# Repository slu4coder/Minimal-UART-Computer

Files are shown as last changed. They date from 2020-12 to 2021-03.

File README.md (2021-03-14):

# Minimal UART Computer - older version with EEPROMs

Current version: https://github.com/slu4coder/Minimal-UART-CPU-FLASH-Edition

Hi there, I built my own Computer from scratch - using nothing but TTL chips, because, well, that's what I wanted to do, I guess! I wanted
a CPU that is easy to understand, fun to build and powerful enough to allow for programming educational stuff and little games on it.
Ah, and by the way - it should be as simple as possible - sort of the "Simplest Usable Personal Computer Ever". Well, in case you're
interested, this repo aims to provide you with everything you need to follow my one-and-a-half year journey down this rabbit hole. 

WHAT YOU GET HERE:

  ● Block diagram of the CPU and overview it's instruction set

  ● KiCAD project files with detailed schematics and PCB layout

  ● Gerber files ready to be submitted at any PCB manufacturer of your choice

  ● Bill of material

  ● Images in .bin format of both the ROM and the CPU's control microcode

  ● Source code of the minimal operating system MinOS and several demos and games

  ● Cross-assembler 'asm.exe' running on Windows in order to comfortably write, assemble and upload your own software

TECHNICAL SPECIFICATION:

  ● Comparable to Altair 8800 or Apple 1

  ● Clear(est?) and simple(st? – you judge!) design for fun and education

  ● 8-bit data bus, 16-bit address bus, Von-Neumann architecture

  ● 64 instructions (conditional branching, subroutines, stack and word ops)

  ● 1,8432MHz clock with 0.25Mips (Altair 8800: 0.29Mips, Apple 1: 0.43Mips)

  ● 24kB RAM / 8kB ROM (OS, memory monitor, disassembler, tools, games)

  ● UART interface (115.2kbps) for terminal display, keyboard input and file I/O

  ● 16 control signals, 2 registers A and B, ALU (arithmetic and logic unit) = simple adder, 3 flags (negative, carry and zero)

  ● Built from 74HCxx TTL logic on 120mm x 190mm PCB

I hope you find this information useful, educational or otherwise interesting. I'd love to hear about you build, so meet me on YouTube.

https://www.youtube.com/channel/UCXYQcMpUBT3aaQKfmAVJNow

Cheers,
Slu4

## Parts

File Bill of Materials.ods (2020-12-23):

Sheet: BOM sorted by reference
Ref | Value | Footprint
C1-C9 | 100nF | Capacitor_THT:C_Disc_D5.0mm_W2.5mm_P2.50mm
C10 | 100pF | Capacitor_THT:C_Disc_D5.0mm_W2.5mm_P2.50mm
C11-C51 | 100nF | Capacitor_THT:C_Disc_D5.0mm_W2.5mm_P2.50mm
C52 | 47µF | Capacitor_THT:CP_Radial_D7.5mm_P2.50mm
J1 | UART | Connector_PinSocket_1x06_P2.54mm_Vertical
R1-R8 | 470 | Resistor_THT_Axial_L6.3mm_D2.5mm_P7.62mm_Horizontal
R9 | 10k | Resistor_THT_Axial_L6.3mm_D2.5mm_P7.62mm_Horizontal
R10 | jumper wire | Resistor_THT_Axial_L6.3mm_D2.5mm_P7.62mm_Horizontal
SW1 | RESET | Button_Switch_THT:SW_PUSH_6mm
U1 | 74HC04 | Package_DIP:DIP-14_W7.62mm
U2 | 74HC173 | Package_DIP:DIP-16_W7.62mm
U3 | 74HC173 | Package_DIP:DIP-16_W7.62mm
U4 | 74HC245 | Package_DIP:DIP-20_W7.62mm
U5 | 74HC173 | Package_DIP:DIP-16_W7.62mm
U6 | 74HC173 | Package_DIP:DIP-16_W7.62mm
U7 | AT28C64B CTRL MSB | Package_DIP:DIP-28_W15.24mm_Socket
U8 | 74HC173 | Package_DIP:DIP-16_W7.62mm
U9 | AT28C64B CTRL LSB | Package_DIP:DIP-28_W15.24mm_Socket
U10 | 74HC173 | Package_DIP:DIP-16_W7.62mm
U11 | 74HC161 | Package_DIP:DIP-16_W7.62mm
U12 | 74HC86 | Package_DIP:DIP-14_W7.62mm
U13 | 74HC283 | Package_DIP:DIP-16_W7.62mm
U14 | 74HC283 | Package_DIP:DIP-16_W7.62mm
U15 | 74HC245 | Package_DIP:DIP-20_W7.62mm
U16 | 74HC86 | Package_DIP:DIP-14_W7.62mm
U17 | 74HC173 | Package_DIP:DIP-16_W7.62mm
U18 | 74HC02 | Package_DIP:DIP-14_W7.62mm
U19 | 74HC08 | Package_DIP:DIP-14_W7.62mm
U23 | 74HC245 | Package_DIP:DIP-20_W7.62mm
U24 | 74HC32 | Package_DIP:DIP-14_W7.62mm
U26 | 74HC161 | Package_DIP:DIP-16_W7.62mm
U28 | 74HC161 | Package_DIP:DIP-16_W7.62mm
U29 | 74HC32 | Package_DIP:DIP-14_W7.62mm
U30 | 74HC161 | Package_DIP:DIP-16_W7.62mm
U31 | AT28C64B 8k ROM | Package_DIP:DIP-28_W15.24mm_Socket
U32 | CY62256 32k RAM | Package_DIP:DIP-28_W15.24mm
U33 | 74HC161 | Package_DIP:DIP-16_W7.62mm
U34 | 74HC161 | Package_DIP:DIP-16_W7.62mm
U35 | 74HC00 | Package_DIP:DIP-14_W7.62mm
U36 | 74HC173 | Package_DIP:DIP-16_W7.62mm
U37 | 74HC193 | Package_DIP:DIP-16_W7.62mm
U38 | 74HC173 | Package_DIP:DIP-16_W7.62mm
U39 | 74HC164 | Package_DIP:DIP-14_W7.62mm
U40 | 74HC02 | Package_DIP:DIP-14_W7.62mm
U41 | 74HC173 | Package_DIP:DIP-16_W7.62mm
U42 | 74HC161 | Package_DIP:DIP-16_W7.62mm
U43 | 74HC165 | Package_DIP:DIP-16_W7.62mm
U44 | 74HC00 | Package_DIP:DIP-14_W7.62mm
U45 | 74HC165 | Package_DIP:DIP-16_W7.62mm
U46 | 74HC161 | Package_DIP:DIP-16_W7.62mm
U48 | 74HC32 | Package_DIP:DIP-14_W7.62mm
U49 | 74HC161 | Package_DIP:DIP-16_W7.62mm
U50 | 74HC245 | Package_DIP:DIP-20_W7.62mm
U51 | 74HC161 | Package_DIP:DIP-16_W7.62mm
U52 | 74HC161 | Package_DIP:DIP-16_W7.62mm
U53 | 74HC245 | Package_DIP:DIP-20_W7.62mm
X1 | ACO-1.8432MHz | Oscillator:Oscillator_DIP-14

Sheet: BOM sorted by value
Qty | Value | Footprint
47 | 100nF | Capacitor_THT:C_Disc_D5.0mm_W2.5mm_P2.50mm
1 | 100pF | Capacitor_THT:C_Disc_D5.0mm_W2.5mm_P2.50mm
1 | 47µF | Capacitor_THT:CP_Radial_D7.5mm_P2.50mm
1 | UART | Connector_PinSocket_2.54mm:PinSocket_1x06_P2.54mm_Vertical
8 | 470 | Resistor_THT:R_Axial_DIN0207_L6.3mm_D2.5mm_P7.62mm_Horizontal
1 | 10k | Resistor_THT:R_Axial_DIN0207_L6.3mm_D2.5mm_P7.62mm_Horizontal
1 | jumper wire | Resistor_THT:R_Axial_DIN0207_L6.3mm_D2.5mm_P7.62mm_Horizontal
1 | RESET | Button_Switch_THT:SW_PUSH_6mm
1 | 74HC04 | Package_DIP:DIP-14_W7.62mm
10 | 74HC173 | Package_DIP:DIP-16_W7.62mm
5 | 74HC245 | Package_DIP:DIP-20_W7.62mm
11 | 74HC161 | Package_DIP:DIP-16_W7.62mm
2 | 74HC86 | Package_DIP:DIP-14_W7.62mm
2 | 74HC283 | Package_DIP:DIP-16_W7.62mm
2 | 74HC02 | Package_DIP:DIP-14_W7.62mm
1 | 74HC08 | Package_DIP:DIP-14_W7.62mm
3 | 74HC32 | Package_DIP:DIP-14_W7.62mm
3 | AT28C64B 8k EEPROM | Package_DIP:DIP-28_W15.24mm
3 | DIP-28_W15.24mm_Socket | Package_DIP:DIP-28_W15.24mm_Socket
1 | CY62256 32k RAM | Package_DIP:DIP-28_W15.24mm
2 | 74HC00 | Package_DIP:DIP-14_W7.62mm
1 | 74HC193 | Package_DIP:DIP-16_W7.62mm
1 | 74HC164 | Package_DIP:DIP-14_W7.62mm
2 | 74HC165 | Package_DIP:DIP-16_W7.62mm
1 | ACO-1.8432MHz | Oscillator:Oscillator_DIP-14

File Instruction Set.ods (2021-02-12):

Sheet: Overview
Version 1.2.0 | Legend: | not applicable |  | not implemented |  | implemented
Description | Accumulator No Operand | Accumulator Immediate | Accumulator Abs Address | Accumulator Rel Address | Byte at Abs Address | Word at Abs Address | Stack at SP + Offset | 64
Load A from |  | LDI | LDA | LDR |  |  | LDS |  | 1 | 1 | 1 |  |  | 1
Store A to |  |  | STA | STR |  |  | STS |  |  | 1 | 1 |  |  | 1
Clear |  |  |  |  | CLB | CLW |  |  |  |  |  | 1 | 1
Negate | NEG |  |  |  | NEB | NEW |  | 1 |  |  |  | 1 | 1
Increment | INC |  |  |  | INB | INW |  | 1 |  |  |  | 1 | 1
Decrement | DEC |  |  |  | DEB | DEW |  | 1 |  |  |  | 1 | 1
Add |  | ADI | ADA | ADR | ADB | ADW |  |  | 1 | 1 | 1 | 1 | 1
Subtract |  | SBI | SBA | SBR | SBB | SBW |  |  | 1 | 1 | 1 | 1 | 1
Compare |  | CPI | CPA | CPR |  |  |  |  | 1 | 1 | 1
Add with Carry In |  | ACI | ACA | ACR | ACB | ACW |  |  | 1 | 1 | 1 | 1 | 1
Subtract with Carry In |  | SCI | SCA | SCR | SCB | SCW |  |  | 1 | 1 | 1 | 1 | 1
Jump to |  |  | JPA | JPR |  |  |  |  |  | 1 | 1
Jump to Subroutine |  |  | JPS |  |  |  |  |  |  | 1
Return from Subroutine | RTS |  |  |  |  |  |  | 1
No Operation (16 clocks) | NOP |  |  |  |  |  |  | 1
Terminal Input | INP |  |  |  |  |  |  | 1
Wait on Terminal Input | WIN |  |  |  |  |  |  | 1
Output A to Terminal | OUT |  |  |  |  |  |  | 1
Clear Carry In Flag | CLC |  |  |  |  |  |  | 1
Set Carry In Flag | SEC |  | Description |  | Accumulator No Operand | Accumulator Immediate | Accumulator Abs Address | 1
Logical Shift Left (= ASL) | LSL |  |  |  |  |  |  | 1
Rotate Shift Left | ROL |  | Branch on Non-Zero |  |  |  | BNE | 1 |  |  |  |  |  | 1
Logical Shift Right | LSR |  | Branch on Zero |  |  |  | BEQ | 1 |  |  |  |  |  | 1
Rotate Shift Right | ROR |  | Branch on Carry Clear |  |  |  | BCC | 1 |  |  |  |  |  | 1
Arithmetic Shift Right | ASR |  | Branch on Carry Set |  |  |  | BCS | 1 |  |  |  |  |  | 1
Push on Stack | PHS |  | Branch on Plus |  |  |  | BPL | 1 |  |  |  |  |  | 1
Pull from Stack | PLS |  | Branch on Minus |  |  |  | BMI | 1 |  |  |  |  |  | 1

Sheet: Properties
Version 1.2.0 |  |  |  | Legend: A=accumulator, R=result, M=most significant byte, ?=undefined, -=unchanged
Instruction | Code |  | Description | Target | Operand |  | Accumulator | Flags |  |  | Clock
Name | DEC | HEX |  |  | Type | Size | Change | N | C | Z | Cycles
NOP | 0 | 00 | No Operation | none | none | 0 | none | - | - | - | 16
WIN | 1 | 01 | Wait on Terminal Input | A | UART | 0 | result | A | 0 | A | n/a
OUT | 2 | 02 | Output to Terminal | UART | A | 0 | none | 1 | 0 | 0 | 6
CLC | 3 | 03 | Clear Carry In Flag | none | none | 0 | none | 1 | 0 | 0 | 5
SEC | 4 | 04 | Set Carry In Flag | none | none | 0 | none | 0 | 1 | 1 | 5
LSL | 5 | 05 | Logical Shift Left (=ASL) | A | none | 0 | result | R | R | R | 5
ROL | 6 | 06 | Rotate Shift Left | A | none | 0 | result | R | R | R | 5
LSR | 7 | 07 | Logical Shift Right | A | none | 0 | result | R | R | R | 13
ROR | 8 | 08 | Rotate Shift Right | A | none | 0 | result | R | R | R | 12
ASR | 9 | 09 | Arithmetic Shift Right | A | none | 0 | result | R | R | R | 15
INP | 10 | 0A | Clear | A | none | 0 | result | 1 | 0 | 0 | 6
NEG | 11 | 0B | Negate | A | none | 0 | result | A | ? | A | 6
INC | 12 | 0C | Increment | A | none | 0 | result | R | R | R | 5
DEC | 13 | 0D | Decrement | A | none | 0 | result | R | R | R | 5
LDI | 14 | 0E | Load from | A | immediate | 1 | result | - | - | - | 4
ADI | 15 | 0F | Add | A | immediate | 1 | result | R | R | R | 5
SBI | 16 | 10 | Subtract | A | immediate | 1 | result | R | R | R | 5
CPI | 17 | 11 | Compare | A | immediate | 1 | none | R | R | R | 5
ACI | 18 | 12 | Add with Carry In | A | immediate | 1 | result | R | R | R | 5
SCI | 19 | 13 | Subtract with Carry In | A | immediate | 1 | result | R | R | R | 5
JPA | 20 | 14 | Jump to | PC | abs address | 2 | none | - | - | - | 6
LDA | 21 | 15 | Load from | A | abs address | 2 | result | - | - | - | 7
STA | 22 | 16 | Store A to | byte @ | abs address | 2 | none | - | - | - | 8
ADA | 23 | 17 | Add | A | abs address | 2 | result | R | R | R | 8
SBA | 24 | 18 | Subtract | A | abs address | 2 | result | R | R | R | 8
CPA | 25 | 19 | Compare | A | abs address | 2 | none | R | R | R | 8
ACA | 26 | 1A | Add with Carry In | A | abs address | 2 | result | R | R | R | 8
SCA | 27 | 1B | Subtract with Carry In | A | abs address | 2 | result | R | R | R | 8
JPR | 28 | 1C | Jump to | PC | rel address | 2 | none | - | - | - | 9
LDR | 29 | 1D | Load from | A | rel address | 2 | result | - | - | - | 10
STR | 30 | 1E | Store A to | byte @ | rel address | 2 | none | - | - | - | 10
ADR | 31 | 1F | Add | A | rel address | 2 | result | R | R | R | 11
SBR | 32 | 20 | Subtract | A | rel address | 2 | result | R | R | R | 11
CPR | 33 | 21 | Compare | A | rel address | 2 | none | R | R | R | 11
ACR | 34 | 22 | Add with Carry In | A | rel address | 2 | result | R | R | R | 11
SCR | 35 | 23 | Subtract with Carry In | A | rel address | 2 | result | R | R | R | 11
CLB | 36 | 24 | Clear | byte @ | abs address | 2 | like target | 0 | 1 | 0 | 8
NEB | 37 | 25 | Negate | byte @ | abs address | 2 | like target | A | ? | A | 10
INB | 38 | 26 | Increment | byte @ | abs address | 2 | like target | R | R | R | 10
DEB | 39 | 27 | Decrement | byte @ | abs address | 2 | like target | R | R | R | 10
ADB | 40 | 28 | Add | byte @ | abs address | 2 | none | R | R | R | 9
SBB | 41 | 29 | Subtract | byte @ | abs address | 2 | none | R | R | R | 10
ACB | 42 | 2A | Add with Carry In | byte @ | abs address | 2 | none | R | R | R | 9
SCB | 43 | 2B | Subtract with Carry In | byte @ | abs address | 2 | none | R | R | R | 10
CLW | 44 | 2C | Clear | word @ | abs address | 2 | none | 0 | 1 | 0 | 10
NEW | 45 | 2D | Negate | word @ | abs address | 2 | not preserved | M | ? | M | 12
INW | 46 | 2E | Increment | word @ | abs address | 2 | not preserved | M | M | M | 12
DEW | 47 | 2F | Decrement | word @ | abs address | 2 | not preserved | M | M | M | 12
ADW | 48 | 30 | Add | word @ | abs address | 2 | not preserved | M | M | M | 11
SBW | 49 | 31 | Subtract | word @ | abs address | 2 | not preserved | M | M | M | 12
ACW | 50 | 32 | Add with Carry In | word @ | abs address | 2 | not preserved | M | M | M | 12
SCW | 51 | 33 | Subtract with Carry In | word @ | abs address | 2 | not preserved | M | M | M | 13
LDS | 52 | 34 | Load from Stack | A | offset | 1 | result | ? | ? | ? | 9
STS | 53 | 35 | Store A on Stack | stack | offset | 1 | none | ? | ? | ? | 16
PHS | 54 | 36 | Push on Stack | stack | none | 0 | none | ? | ? | ? | 12
PLS | 55 | 37 | Pull from Stack | A | none | 0 | result | ? | ? | ? | 10
JPS | 56 | 38 | Jump to Subroutine | PC | abs address | 2 | not preserved | ? | ? | ? | 16
RTS | 57 | 39 | Return from Subroutine | PC | none | 0 | not preserved | ? | ? | ? | 14
BNE | 58 | 3A | Branch on Non-Zero | PC | abs address | 2 | none | - | - | - | 5/6
BEQ | 59 | 3B | Branch on Zero | PC | abs address | 2 | none | - | - | - | 5/6
BCC | 60 | 3C | Branch on Carry Clear | PC | abs address | 2 | none | - | - | - | 5/6
BCS | 61 | 3D | Branch on Carry Set | PC | abs address | 2 | none | - | - | - | 5/6
BPL | 62 | 3E | Branch on Plus | PC | abs address | 2 | none | - | - | - | 5/6
BMI | 63 | 3F | Branch on Minus | PC | abs address | 2 | none | - | - | - | 5/6

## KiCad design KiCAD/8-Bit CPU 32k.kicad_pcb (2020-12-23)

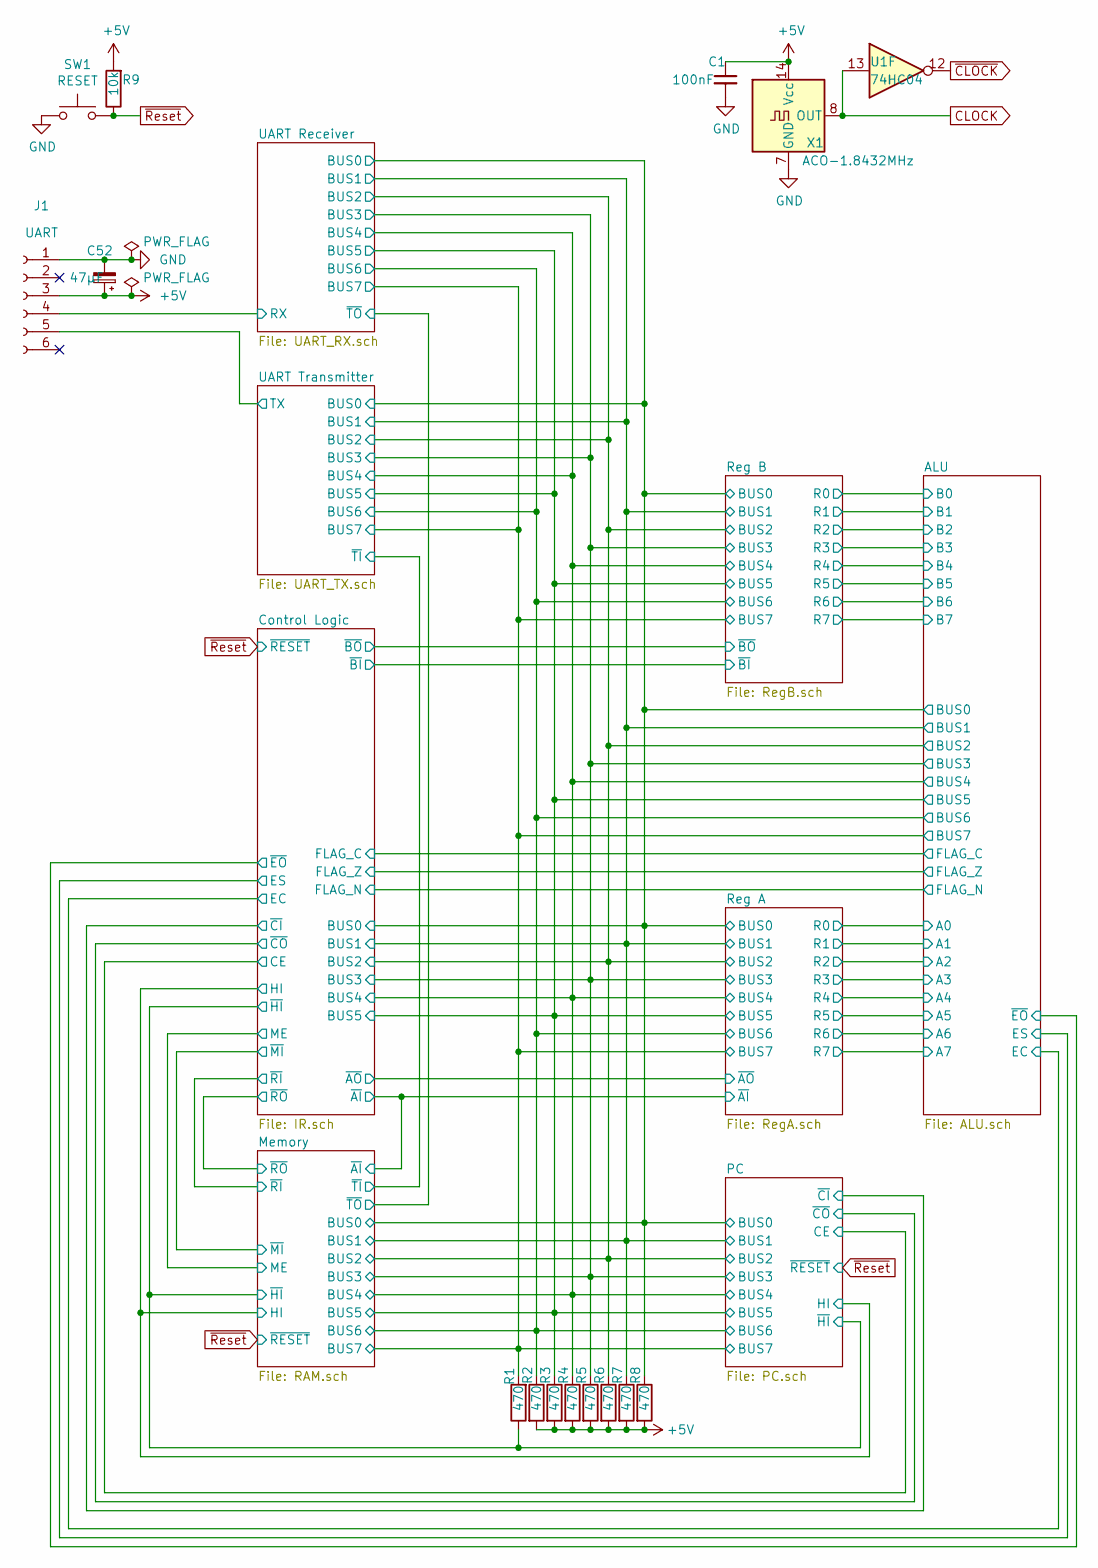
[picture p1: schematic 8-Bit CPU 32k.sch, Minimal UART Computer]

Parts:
C1: 100nF; C_Disc_D5.0mm_W2.5mm_P2.50mm
C52: 47µF; CP_Radial_D7.5mm_P2.50mm
J1: UART; PinSocket_1x06_P2.54mm_Vertical
R1, R2, R3, R4, R5, R6, R7, R8: 470; R_Axial_DIN0207_L6.3mm_D2.5mm_P7.62mm_Horizontal
R9: 10k; R_Axial_DIN0207_L6.3mm_D2.5mm_P7.62mm_Horizontal
SW1: RESET; SW_PUSH_6mm
U1: 74HC04; DIP-14_W7.62mm
X1: ACO-1.8432MHz; Oscillator_DIP-14

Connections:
+5V: C1.1, C52.1, J1.3, R2.2, R3.2, R4.2, R5.2, R6.2, R7.2, R8.2, R9.2, X1.14 (Vcc); also elsewhere on the board
/ALU/BUS0: R8.1; also elsewhere on the board
/ALU/BUS1: R7.1; also elsewhere on the board
/ALU/BUS2: R6.1; also elsewhere on the board
/ALU/BUS3: R5.1; also elsewhere on the board
/ALU/BUS4: R4.1; also elsewhere on the board
/ALU/BUS5: R3.1; also elsewhere on the board
/ALU/BUS6: R2.1; also elsewhere on the board
/ALU/BUS7: R1.2; also elsewhere on the board
/Control Logic/~HI: R1.1; also elsewhere on the board
/UART Receiver/RX: J1.4; also elsewhere on the board
/UART Transmitter/TX: J1.5; also elsewhere on the board
CLOCK: U1.13, X1.8 (OUT); also elsewhere on the board
GND: C1.2, C52.2, J1.1, SW1.1, X1.7 (GND); also elsewhere on the board
~CLOCK: U1.12; also elsewhere on the board
~Reset: R9.1, SW1.2; also elsewhere on the board

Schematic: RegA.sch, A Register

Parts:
C2, C3, C4: 100nF; C_Disc_D5.0mm_W2.5mm_P2.50mm
U2, U3: 74HC173; DIP-16_W7.62mm
U4: 74HC245; DIP-20_W7.62mm

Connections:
+5V: C2.1, C3.1, C4.1, U2.16, U3.16, U4.1 (A->B), U4.20 (VCC); also elsewhere on the board
/ALU/A0: U3.3, U4.2 (A0); also elsewhere on the board
/ALU/A1: U3.4, U4.3 (A1); also elsewhere on the board
/ALU/A2: U3.5, U4.4 (A2); also elsewhere on the board
/ALU/A3: U3.6, U4.5 (A3); also elsewhere on the board
/ALU/A4: U2.3, U4.6 (A4); also elsewhere on the board
/ALU/A5: U2.4, U4.7 (A5); also elsewhere on the board
/ALU/A6: U2.5, U4.8 (A6); also elsewhere on the board
/ALU/A7: U2.6, U4.9 (A7); also elsewhere on the board
/ALU/BUS0: U3.14, U4.18 (B0); also elsewhere on the board
/ALU/BUS1: U3.13, U4.17 (B1); also elsewhere on the board
/ALU/BUS2: U3.12, U4.16 (B2); also elsewhere on the board
/ALU/BUS3: U3.11, U4.15 (B3); also elsewhere on the board
/ALU/BUS4: U2.14, U4.14 (B4); also elsewhere on the board
/ALU/BUS5: U2.13, U4.13 (B5); also elsewhere on the board
/ALU/BUS6: U2.12, U4.12 (B6); also elsewhere on the board
/ALU/BUS7: U2.11, U4.11 (B7); also elsewhere on the board
/Control Logic/~AI: U2.9, U2.10, U3.9, U3.10; also elsewhere on the board
/Control Logic/~AO: U4.19 (CE); also elsewhere on the board
CLOCK: U2.7, U3.7; also elsewhere on the board
GND: C2.2, C3.2, C4.2, U2.1, U2.2, U2.8, U2.15, U3.1, U3.2, U3.8, U3.15, U4.10 (GND); also elsewhere on the board

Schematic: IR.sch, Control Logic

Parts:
C5, C6, C7, C8, C9, C11: 100nF; C_Disc_D5.0mm_W2.5mm_P2.50mm
C10: 100pF; C_Disc_D5.0mm_W2.5mm_P2.50mm
R10: wire; R_Axial_DIN0207_L6.3mm_D2.5mm_P7.62mm_Horizontal
U1: 74HC04; DIP-14_W7.62mm
U5, U6, U8: 74HC173; DIP-16_W7.62mm
U7: AT28C64B CTRL MSB; DIP-28_W15.24mm_Socket
U9: AT28C64B CTRL LSB; DIP-28_W15.24mm_Socket
U11: 74HC161; DIP-16_W7.62mm
U19: 74HC08; DIP-14_W7.62mm

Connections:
+5V: C5.1, C6.1, C7.1, C8.1, C9.1, C11.1, U5.16, U6.16, U7.27, U7.28, U8.16, U9.27, U9.28, U11.7, U11.9, U11.10, U11.16; also elsewhere on the board
/ALU/BUS0: U8.14; also elsewhere on the board
/ALU/BUS1: U8.13; also elsewhere on the board
/ALU/BUS2: U8.12; also elsewhere on the board
/ALU/BUS3: U8.11; also elsewhere on the board
/ALU/BUS4: U6.14; also elsewhere on the board
/ALU/BUS5: U6.13; also elsewhere on the board
/ALU/EC: U7.13; also elsewhere on the board
/ALU/ES: U7.12; also elsewhere on the board
/ALU/FLAG_C: U5.13; also elsewhere on the board
/ALU/FLAG_N: U5.12; also elsewhere on the board
/ALU/FLAG_Z: U5.14, U19.6
/ALU/~EO: U5.9, U5.10, U7.11; also elsewhere on the board
/Control Logic/CE: U7.17; also elsewhere on the board
/Control Logic/HI: U1.1, U9.19; also elsewhere on the board
/Control Logic/~AI: U9.15; also elsewhere on the board
/Control Logic/~AO: U9.13; also elsewhere on the board
/Control Logic/~BI: U9.12; also elsewhere on the board
/Control Logic/~BO: U9.11; also elsewhere on the board
/Control Logic/~CI: U7.19; also elsewhere on the board
/Control Logic/~CO: U7.18; also elsewhere on the board
/Control Logic/~HI: U1.2; also elsewhere on the board
/Control Logic/~MI: U9.18; also elsewhere on the board
/Control Logic/~RI: U9.17; also elsewhere on the board
/Control Logic/~RO: U9.16; also elsewhere on the board
CLOCK: U5.7, U6.7, U8.7; also elsewhere on the board
GND: C5.2, C6.2, C7.2, C8.2, C9.2, C10.2, C11.2, U5.1, U5.2, U5.8, U5.11, U5.15, U6.1, U6.2, U6.8, U6.11, U6.12, U6.15, U7.14, U7.20, U7.22, U8.1, U8.2, U8.8, U8.15, U9.14, U9.20, U9.22, U11.8; also elsewhere on the board
unnamed: C10.1, R10.2, U19.10
unnamed: R10.1, U7.15
unnamed: U5.3, U7.21, U9.21
unnamed: U5.4, U7.23, U9.23
unnamed: U5.5, U7.2, U9.2
unnamed: U6.3, U7.25, U9.25
unnamed: U6.4, U7.24, U9.24
unnamed: U6.9, U6.10, U7.16, U8.9, U8.10
unnamed: U7.3, U8.6, U9.3
unnamed: U7.4, U8.5, U9.4
unnamed: U7.5, U8.4, U9.5
unnamed: U7.6, U8.3, U9.6
unnamed: U11.1, U19.8
unnamed: U7.7, U9.7, U11.11
unnamed: U7.8, U9.8, U11.12
unnamed: U7.9, U9.9, U11.13
unnamed: U7.10, U9.10, U11.14
unnamed 105: U19.1; also elsewhere on the board
unnamed 106: U19.2; also elsewhere on the board
unnamed 107: U19.12; also elsewhere on the board
unnamed 108: U19.13; also elsewhere on the board
unnamed: U19.3, U19.4
unnamed: U19.5, U19.11
~CLOCK: U11.2; also elsewhere on the board
~Reset: U19.9; also elsewhere on the board

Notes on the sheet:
~IC
~II
~FI

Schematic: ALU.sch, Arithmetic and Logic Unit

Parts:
C12, C13, C14, C16, C17, C18: 100nF; C_Disc_D5.0mm_W2.5mm_P2.50mm
U12, U16: 74HC86; DIP-14_W7.62mm
U13, U14: 74HC283; DIP-16_W7.62mm
U15: 74HC245; DIP-20_W7.62mm
U18: 74HC02; DIP-14_W7.62mm
U19: 74HC08; DIP-14_W7.62mm

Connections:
+5V: C12.1, C13.1, C14.1, C16.1, C17.1, C18.1, U12.14 (VCC), U13.16, U14.16, U15.20 (VCC), U16.14 (VCC), U18.14 (VCC), U19.14 (VCC); also elsewhere on the board
/ALU/A0: U14.5; also elsewhere on the board
/ALU/A1: U14.3; also elsewhere on the board
/ALU/A2: U14.14; also elsewhere on the board
/ALU/A3: U14.12; also elsewhere on the board
/ALU/A4: U13.5; also elsewhere on the board
/ALU/A5: U13.3; also elsewhere on the board
/ALU/A6: U13.14; also elsewhere on the board
/ALU/A7: U13.12; also elsewhere on the board
/ALU/B0: U16.13; also elsewhere on the board
/ALU/B1: U16.10; also elsewhere on the board
/ALU/B2: U16.5; also elsewhere on the board
/ALU/B3: U16.2; also elsewhere on the board
/ALU/B4: U12.13; also elsewhere on the board
/ALU/B5: U12.10; also elsewhere on the board
/ALU/B6: U12.5; also elsewhere on the board
/ALU/B7: U12.2; also elsewhere on the board
/ALU/BUS0: U15.2 (A0); also elsewhere on the board
/ALU/BUS1: U15.3 (A1); also elsewhere on the board
/ALU/BUS2: U15.4 (A2); also elsewhere on the board
/ALU/BUS3: U15.5 (A3); also elsewhere on the board
/ALU/BUS4: U15.6 (A4); also elsewhere on the board
/ALU/BUS5: U15.7 (A5); also elsewhere on the board
/ALU/BUS6: U15.8 (A6); also elsewhere on the board
/ALU/BUS7: U15.9 (A7); also elsewhere on the board
/ALU/EC: U14.7; also elsewhere on the board
/ALU/ES: U12.1, U12.4, U12.9, U12.12, U16.1, U16.4, U16.9, U16.12; also elsewhere on the board
/ALU/FLAG_C: U13.9; also elsewhere on the board
/ALU/FLAG_N: U13.10, U15.11 (B7), U18.12; also elsewhere on the board
/ALU/FLAG_Z: U19.6; also elsewhere on the board
/ALU/~EO: U15.19 (CE); also elsewhere on the board
GND: C12.2, C13.2, C14.2, C16.2, C17.2, C18.2, U12.7 (GND), U13.8, U14.8, U15.1 (A->B), U15.10 (GND), U16.7 (GND), U18.7 (GND), U19.7 (GND); also elsewhere on the board
unnamed: U12.3, U13.11
unnamed: U12.6, U13.15
unnamed: U12.8, U13.2
unnamed: U12.11, U13.6
unnamed: U13.1, U15.13 (B5), U18.9
unnamed: U13.4, U15.14 (B4), U18.8
unnamed: U13.7, U14.9
unnamed: U13.13, U15.12 (B6), U18.11
unnamed: U14.1, U15.17 (B1), U18.3
unnamed: U14.2, U16.8
unnamed: U14.4, U15.18 (B0), U18.2
unnamed: U14.6, U16.11
unnamed: U14.10, U15.15 (B3), U18.6
unnamed: U14.11, U16.3
unnamed: U14.13, U15.16 (B2), U18.5
unnamed: U14.15, U16.6
unnamed: U18.1, U19.1
unnamed: U18.4, U19.2
unnamed: U18.10, U19.12
unnamed: U18.13, U19.13
unnamed: U19.3, U19.4
unnamed: U19.5, U19.11

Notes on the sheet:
C=100nF intentionally left out due to layout.

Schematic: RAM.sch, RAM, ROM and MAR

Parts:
C22, C23, C24, C25, C26, C27, C28, C29, C31: 100nF; C_Disc_D5.0mm_W2.5mm_P2.50mm
U1: 74HC04; DIP-14_W7.62mm
U24, U29: 74HC32; DIP-14_W7.62mm
U26, U28, U30, U33: 74HC161; DIP-16_W7.62mm
U31: AT28C64B 8k ROM; DIP-28_W15.24mm_Socket
U32: CY62256 32k RAM; DIP-28_W15.24mm
U44: 74HC00; DIP-14_W7.62mm

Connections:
+5V: C22.1, C23.1, C24.1, C25.1, C26.1, C27.1, C28.1, C29.1, C31.1, U1.14 (VCC), U24.14, U26.1, U26.16, U28.1, U28.16, U29.14, U30.16, U31.27, U31.28, U32.28, U33.16; also elsewhere on the board
/ALU/BUS0: U28.3, U31.11, U32.11, U33.3; also elsewhere on the board
/ALU/BUS1: U28.4, U31.12, U32.12, U33.4; also elsewhere on the board
/ALU/BUS2: U28.5, U31.13, U32.13, U33.5; also elsewhere on the board
/ALU/BUS3: U28.6, U31.15, U32.15, U33.6; also elsewhere on the board
/ALU/BUS4: U26.3, U30.3, U31.16, U32.16; also elsewhere on the board
/ALU/BUS5: U26.4, U30.4, U31.17, U32.17; also elsewhere on the board
/ALU/BUS6: U26.5, U30.5, U31.18, U32.18; also elsewhere on the board
/ALU/BUS7: U26.6, U30.6, U31.19, U32.19; also elsewhere on the board
/Control Logic/CE: U26.7, U28.7, U30.7, U33.7, U33.10; also elsewhere on the board
/Control Logic/HI: U24.1; also elsewhere on the board
/Control Logic/~AI: U29.13; also elsewhere on the board
/Control Logic/~HI: U24.5; also elsewhere on the board
/Control Logic/~MI: U24.2, U24.4; also elsewhere on the board
/Control Logic/~RI: U1.11, U29.9; also elsewhere on the board
/Control Logic/~RO: U24.13, U31.22, U32.22; also elsewhere on the board
/Memory/M0: U31.10, U32.21, U33.14
/Memory/M1: U31.9, U32.23, U33.13
/Memory/M2: U31.8, U32.24, U33.12
/Memory/M3: U31.7, U32.25, U33.11
/Memory/M4: U30.14, U31.6, U32.26
/Memory/M5: U30.13, U31.5, U32.1
/Memory/M6: U30.12, U31.4, U32.2
/Memory/M7: U30.11, U31.3, U32.3
/Memory/M8: U28.14, U31.25, U32.4
/Memory/M9: U28.13, U31.24, U32.5
/Memory/M10: U28.12, U31.21, U32.6
/Memory/M11: U28.11, U31.23, U32.7
/Memory/M12: U26.14, U31.2, U32.8
/Memory/M13: U26.13, U29.1, U32.9
/Memory/M14: U26.12, U29.2, U32.10
/Memory/M15: U1.9, U24.9, U26.11, U29.5
/Memory/~TI: U29.8; also elsewhere on the board
/Memory/~TO: U29.11; also elsewhere on the board
CLOCK: U26.2, U28.2, U30.2, U33.2, U44.9; also elsewhere on the board
GND: C22.2, C23.2, C24.2, C25.2, C26.2, C27.2, C28.2, C29.2, C31.2, U1.7 (GND), U24.7, U26.8, U28.8, U29.7, U30.8, U31.14, U32.14, U33.8; also elsewhere on the board
unnamed: U1.5, U29.6, U31.20
unnamed: U1.6, U24.10
unnamed: U1.8, U24.12, U29.10
unnamed: U1.10, U44.10
unnamed: U24.3, U30.9, U33.9
unnamed: U24.6, U26.9, U28.9
unnamed: U24.8, U32.20
unnamed: U24.11, U29.12
unnamed: U26.10, U28.15
unnamed: U28.10, U30.15
unnamed: U29.3, U29.4
unnamed: U30.10, U33.15
unnamed: U32.27, U44.8
~Reset: U30.1, U33.1; also elsewhere on the board

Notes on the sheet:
~MIL
~MIH
~ROM_ENABLE
~RAM_ENABLE

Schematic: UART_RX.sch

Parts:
C32, C33, C34, C35, C36, C37, C39, C51: 100nF; C_Disc_D5.0mm_W2.5mm_P2.50mm
U1: 74HC04; DIP-14_W7.62mm
U34: 74HC161; DIP-16_W7.62mm
U35: 74HC00; DIP-14_W7.62mm
U36, U38, U41: 74HC173; DIP-16_W7.62mm
U37: 74HC193; DIP-16_W7.62mm
U39: 74HC164; DIP-14_W7.62mm
U40: 74HC02; DIP-14_W7.62mm

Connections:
+5V: C32.1, C33.1, C34.1, C35.1, C36.1, C37.1, C39.1, C51.1, U34.7, U34.9, U34.10, U34.16, U35.14 (VCC), U36.16, U37.5, U37.9, U37.15, U37.16, U38.16, U39.2 (DSB), U39.9 (~MR), U39.14 (VCC), U40.14 (VCC), U41.16; also elsewhere on the board
/ALU/BUS0: U36.6; also elsewhere on the board
/ALU/BUS1: U36.5; also elsewhere on the board
/ALU/BUS2: U36.4; also elsewhere on the board
/ALU/BUS3: U36.3; also elsewhere on the board
/ALU/BUS4: U38.6; also elsewhere on the board
/ALU/BUS5: U38.5; also elsewhere on the board
/ALU/BUS6: U38.4; also elsewhere on the board
/ALU/BUS7: U38.3; also elsewhere on the board
/Memory/~TO: U36.1, U36.2, U38.1, U38.2, U40.8; also elsewhere on the board
/UART Receiver/RX: U35.1, U39.1 (DSA); also elsewhere on the board
/UART Receiver/~RESET: U35.5, U35.9, U37.13
CLOCK: U34.2, U41.7; also elsewhere on the board
GND: C32.2, C33.2, C34.2, C35.2, C36.2, C37.2, C39.2, C51.2, U34.8, U35.7 (GND), U36.8, U36.9, U36.10, U37.1, U37.8, U37.10, U37.14, U38.8, U38.9, U38.10, U39.7 (GND), U40.7 (GND), U41.1, U41.2, U41.8, U41.9, U41.10; also elsewhere on the board
unnamed: U1.3, U41.3
unnamed: U1.4, U40.3
unnamed: U34.1, U35.3, U35.4, U37.11
unnamed: U34.11, U37.4, U39.8 (CP)
unnamed: U35.2, U35.6, U36.7, U38.7
unnamed: U35.10, U35.11
unnamed: U35.8, U35.12, U41.14
unnamed: U35.13, U40.13
unnamed: U36.11, U39.13 (Q7)
unnamed: U36.12, U39.12 (Q6)
unnamed: U36.13, U39.11 (Q5)
unnamed: U36.14, U39.10 (Q4)
unnamed: U36.15, U38.15, U40.10, U40.11, U40.12, U41.15
unnamed: U38.11, U39.6 (Q3)
unnamed: U38.12, U39.5 (Q2)
unnamed: U38.13, U39.4 (Q1)
unnamed: U38.14, U39.3 (Q0)
unnamed: U40.1, U40.5, U40.6
unnamed: U40.4, U40.9
~CLOCK: U40.2; also elsewhere on the board

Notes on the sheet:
DATA_READY

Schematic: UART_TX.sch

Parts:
C40, C41, C42, C43: 100nF; C_Disc_D5.0mm_W2.5mm_P2.50mm
U42: 74HC161; DIP-16_W7.62mm
U43, U45: 74HC165; DIP-16_W7.62mm
U44: 74HC00; DIP-14_W7.62mm

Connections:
+5V: C40.1, C41.1, C42.1, C43.1, U42.7, U42.9, U42.10, U42.16, U43.6, U43.16, U44.14 (VCC), U45.3, U45.4, U45.10, U45.11, U45.12, U45.13, U45.14, U45.16; also elsewhere on the board
/ALU/BUS0: U43.4; also elsewhere on the board
/ALU/BUS1: U43.3; also elsewhere on the board
/ALU/BUS2: U43.14; also elsewhere on the board
/ALU/BUS3: U43.13; also elsewhere on the board
/ALU/BUS4: U43.12; also elsewhere on the board
/ALU/BUS5: U43.11; also elsewhere on the board
/ALU/BUS6: U45.6; also elsewhere on the board
/ALU/BUS7: U45.5; also elsewhere on the board
/Memory/~TI: U44.4, U44.5; also elsewhere on the board
/UART Transmitter/TX: U43.9; also elsewhere on the board
CLOCK: U42.2, U44.2; also elsewhere on the board
GND: C40.2, C41.2, C42.2, C43.2, U42.8, U43.5, U43.8, U44.7 (GND), U44.12, U44.13, U45.8; also elsewhere on the board
unnamed: U42.1, U43.1, U44.3, U45.1
unnamed: U42.11, U43.2, U45.2
unnamed: U43.10, U45.9
unnamed: U43.15, U44.1, U44.6, U45.15

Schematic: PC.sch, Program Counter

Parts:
C44, C45, C46, C47, C48, C49, C50: 100nF; C_Disc_D5.0mm_W2.5mm_P2.50mm
U46, U49, U51, U52: 74HC161; DIP-16_W7.62mm
U48: 74HC32; DIP-14_W7.62mm
U50, U53: 74HC245; DIP-20_W7.62mm

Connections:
+5V: C44.1, C45.1, C46.1, C47.1, C48.1, C49.1, C50.1, U46.16, U48.14, U49.16, U50.20 (VCC), U51.16, U52.16, U53.20 (VCC); also elsewhere on the board
/ALU/BUS0: U49.3, U50.2 (A0), U52.3, U53.2 (A0); also elsewhere on the board
/ALU/BUS1: U49.4, U50.3 (A1), U52.4, U53.3 (A1); also elsewhere on the board
/ALU/BUS2: U49.5, U50.4 (A2), U52.5, U53.4 (A2); also elsewhere on the board
/ALU/BUS3: U49.6, U50.5 (A3), U52.6, U53.5 (A3); also elsewhere on the board
/ALU/BUS4: U46.3, U50.6 (A4), U51.3, U53.6 (A4); also elsewhere on the board
/ALU/BUS5: U46.4, U50.7 (A5), U51.4, U53.7 (A5); also elsewhere on the board
/ALU/BUS6: U46.5, U50.8 (A6), U51.5, U53.8 (A6); also elsewhere on the board
/ALU/BUS7: U46.6, U50.9 (A7), U51.6, U53.9 (A7); also elsewhere on the board
/Control Logic/CE: U46.7, U49.7, U51.7, U52.7, U52.10; also elsewhere on the board
/Control Logic/HI: U48.5, U48.9; also elsewhere on the board
/Control Logic/~CI: U48.10, U48.12; also elsewhere on the board
/Control Logic/~CO: U48.2, U48.4; also elsewhere on the board
/Control Logic/~HI: U48.1, U48.13; also elsewhere on the board
CLOCK: U46.2, U49.2, U51.2, U52.2; also elsewhere on the board
GND: C44.2, C45.2, C46.2, C47.2, C48.2, C49.2, C50.2, U46.8, U48.7, U49.8, U50.1 (A->B), U50.10 (GND), U51.8, U52.8, U53.1 (A->B), U53.10 (GND); also elsewhere on the board
unnamed: U46.9, U48.11, U49.9
unnamed: U46.10, U49.15
unnamed: U46.11, U50.11 (B7)
unnamed: U46.12, U50.12 (B6)
unnamed: U46.13, U50.13 (B5)
unnamed: U46.14, U50.14 (B4)
unnamed: U48.3, U50.19 (CE)
unnamed: U48.6, U53.19 (CE)
unnamed: U48.8, U51.9, U52.9
unnamed: U49.10, U51.15
unnamed: U49.11, U50.15 (B3)
unnamed: U49.12, U50.16 (B2)
unnamed: U49.13, U50.17 (B1)
unnamed: U49.14, U50.18 (B0)
unnamed: U51.10, U52.15
unnamed: U51.11, U53.11 (B7)
unnamed: U51.12, U53.12 (B6)
unnamed: U51.13, U53.13 (B5)
unnamed: U51.14, U53.14 (B4)
unnamed: U52.11, U53.15 (B3)
unnamed: U52.12, U53.16 (B2)
unnamed: U52.13, U53.17 (B1)
unnamed: U52.14, U53.18 (B0)
~Reset: U46.1, U49.1, U51.1, U52.1; also elsewhere on the board

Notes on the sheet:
~COH
~COL
~CIL
~CIH

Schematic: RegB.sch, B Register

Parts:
C19, C20, C21: 100nF; C_Disc_D5.0mm_W2.5mm_P2.50mm
U10, U17: 74HC173; DIP-16_W7.62mm
U23: 74HC245; DIP-20_W7.62mm

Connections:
+5V: C19.1, C20.1, C21.1, U10.16, U17.16, U23.1 (A->B), U23.20 (VCC); also elsewhere on the board
/ALU/B0: U17.3, U23.2 (A0); also elsewhere on the board
/ALU/B1: U17.4, U23.3 (A1); also elsewhere on the board
/ALU/B2: U17.5, U23.4 (A2); also elsewhere on the board
/ALU/B3: U17.6, U23.5 (A3); also elsewhere on the board
/ALU/B4: U10.3, U23.6 (A4); also elsewhere on the board
/ALU/B5: U10.4, U23.7 (A5); also elsewhere on the board
/ALU/B6: U10.5, U23.8 (A6); also elsewhere on the board
/ALU/B7: U10.6, U23.9 (A7); also elsewhere on the board
/ALU/BUS0: U17.14, U23.18 (B0); also elsewhere on the board
/ALU/BUS1: U17.13, U23.17 (B1); also elsewhere on the board
/ALU/BUS2: U17.12, U23.16 (B2); also elsewhere on the board
/ALU/BUS3: U17.11, U23.15 (B3); also elsewhere on the board
/ALU/BUS4: U10.14, U23.14 (B4); also elsewhere on the board
/ALU/BUS5: U10.13, U23.13 (B5); also elsewhere on the board
/ALU/BUS6: U10.12, U23.12 (B6); also elsewhere on the board
/ALU/BUS7: U10.11, U23.11 (B7); also elsewhere on the board
/Control Logic/~BI: U10.9, U10.10, U17.9, U17.10; also elsewhere on the board
/Control Logic/~BO: U23.19 (CE); also elsewhere on the board
CLOCK: U10.7, U17.7; also elsewhere on the board
GND: C19.2, C20.2, C21.2, U10.1, U10.2, U10.8, U10.15, U17.1, U17.2, U17.8, U17.15, U23.10 (GND); also elsewhere on the board

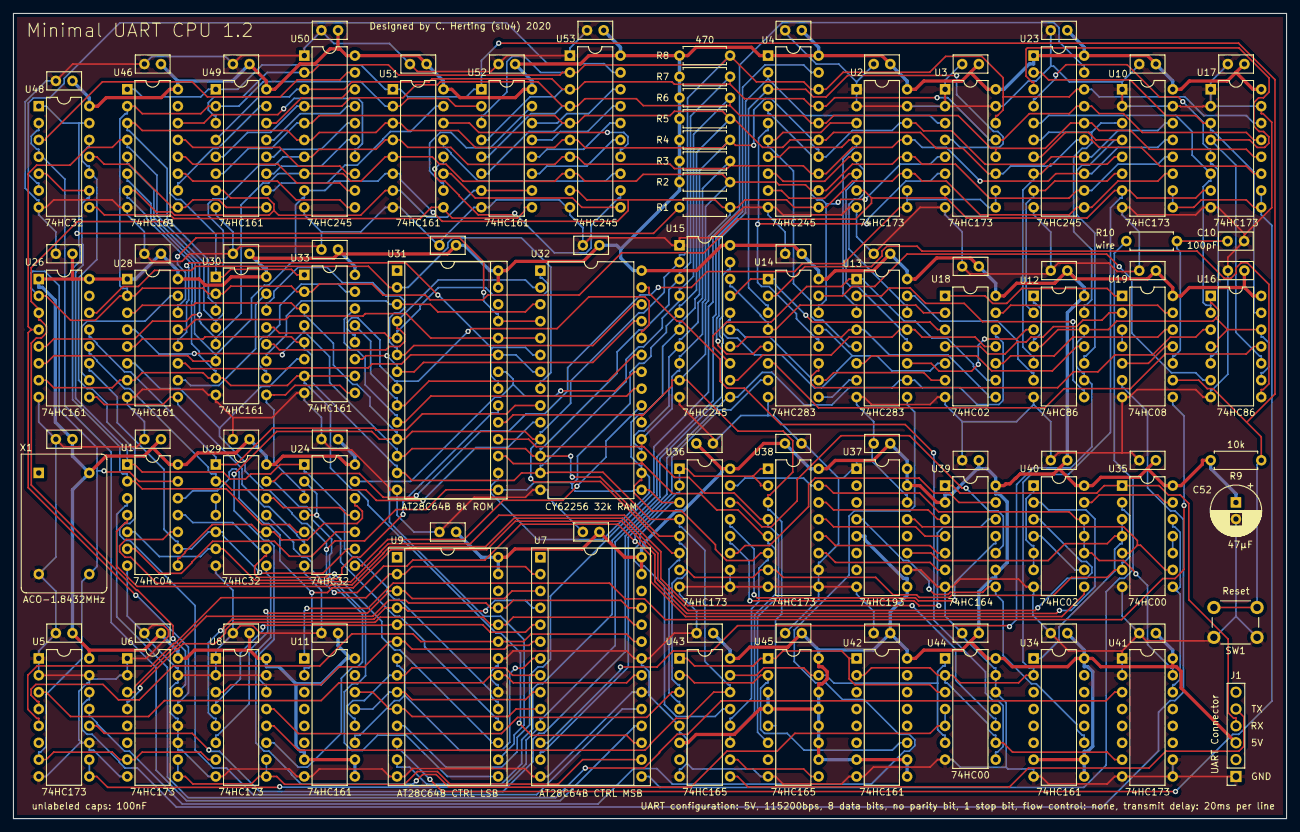
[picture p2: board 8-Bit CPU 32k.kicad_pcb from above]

Board: 2 copper layers, 191.8 x 121.3 mm, 109 parts (0 on the bottom side), 166 nets.

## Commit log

2020-12-14 Revision 1.2
    [Bill of Materials.ods, Instruction Set.ods]
2020-12-23 Revision 1.2.0
    [8-Bit CPU 32k-B_Cu.gbl, 8-Bit CPU 32k-B_Mask.gbs, 8-Bit CPU 32k-B_SilkS.gbo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]
2021-02-12 Revision 1.3
    [Instruction Set.ods]

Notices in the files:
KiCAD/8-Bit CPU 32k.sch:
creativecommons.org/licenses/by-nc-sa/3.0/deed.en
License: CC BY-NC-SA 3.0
